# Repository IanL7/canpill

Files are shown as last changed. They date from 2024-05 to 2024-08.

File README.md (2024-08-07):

# canpill
Canpill is a basic development board based on Phil's Lab stm32 blue pill adaptation (https://www.youtube.com/watch?v=aVUqaB0IMh4). The board uses an STM32F103C8 microcontroller.

This repository contains the kicad project files and some basic software for the board.

## Image
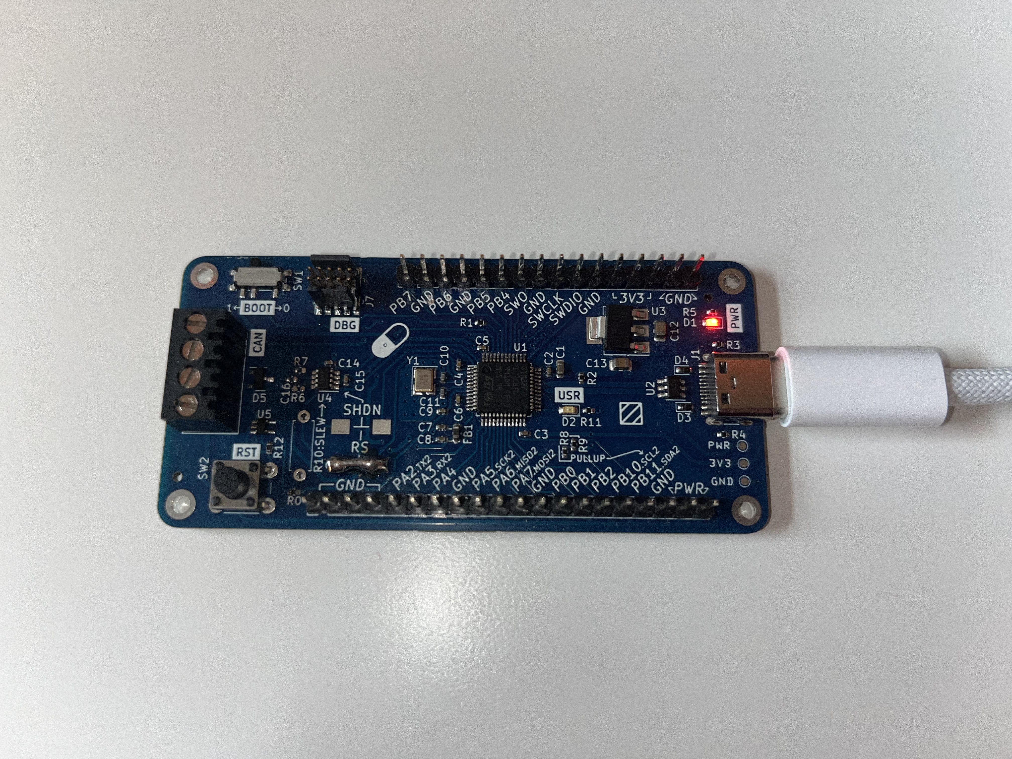
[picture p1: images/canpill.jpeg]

- Board manufactured before R13 was added

## Additions
- A CAN transceiver with screw terminal interface
- Additional header IO breakout
- 10 pin J-Link compatible connector
- Modified layout

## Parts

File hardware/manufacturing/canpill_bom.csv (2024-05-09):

Designator | Qnty | Comment | Footprint
C1 | 1 | 10u | Capacitor_SMD:C_0603_1608Metric
C2, C3, C4, C5, C9, C14, C15 | 7 | 100n | Capacitor_SMD:C_0402_1005Metric
C6 | 1 | 10n | Capacitor_SMD:C_0402_1005Metric
C7, C8 | 2 | 1u | Capacitor_SMD:C_0402_1005Metric
C10, C11 | 2 | 10p | Capacitor_SMD:C_0402_1005Metric
C12, C13 | 2 | 22u | Capacitor_SMD:C_0805_2012Metric
D1 | 1 | RED | LED_SMD:LED_0603_1608Metric
D2 | 1 | GREEN | LED_SMD:LED_0603_1608Metric
D3, D4 | 2 | D_Schottky | Diode_SMD:D_SOD-523
D5 | 1 | NUP2105L | Package_TO_SOT_SMD:SOT-23
FB1 | 1 | 120R | Inductor_SMD:L_0603_1608Metric
J1 | 1 | TYPE-C-31-M-12 | Connector_USB:USB_C_Receptacle_HRO_TYPE-C-31-M-12
R0, R1, R12 | 3 | 10k | Resistor_SMD:R_0402_1005Metric
R2, R5, R11 | 3 | 1k5 | Resistor_SMD:R_0402_1005Metric
R3, R4, R8, R9 | 4 | 5k1 | Resistor_SMD:R_0402_1005Metric
SW1 | 1 | SW_SPDT | Button_Switch_SMD:SW_SPDT_PCM12
SW2 | 1 | SW_Push | Button_Switch_THT:SW_PUSH_6mm
TP1, TP2, TP3 | 3 | TestPoint | TestPoint:TestPoint_Pad_D1.0mm
U1 | 1 | STM32F103C8T6 | Package_QFP:LQFP-48_7x7mm_P0.5mm
U2 | 1 | USBLC6-2SC6 | Package_TO_SOT_SMD:SOT-23-6
U3 | 1 | AMS1117-3.3 | Package_TO_SOT_SMD:SOT-223-3_TabPin2
U4 | 1 | MAX3051EKA+T | Package_TO_SOT_SMD:SOT-23-8
U5 | 1 | 74AHC1G08GW-Q100,1 | 74AHC1G08GW_Q100_1-2:SOT65P210X110-5N
Y1 | 1 | 16MHz | Crystal:Crystal_SMD_3225-4Pin_3.2x2.5mm

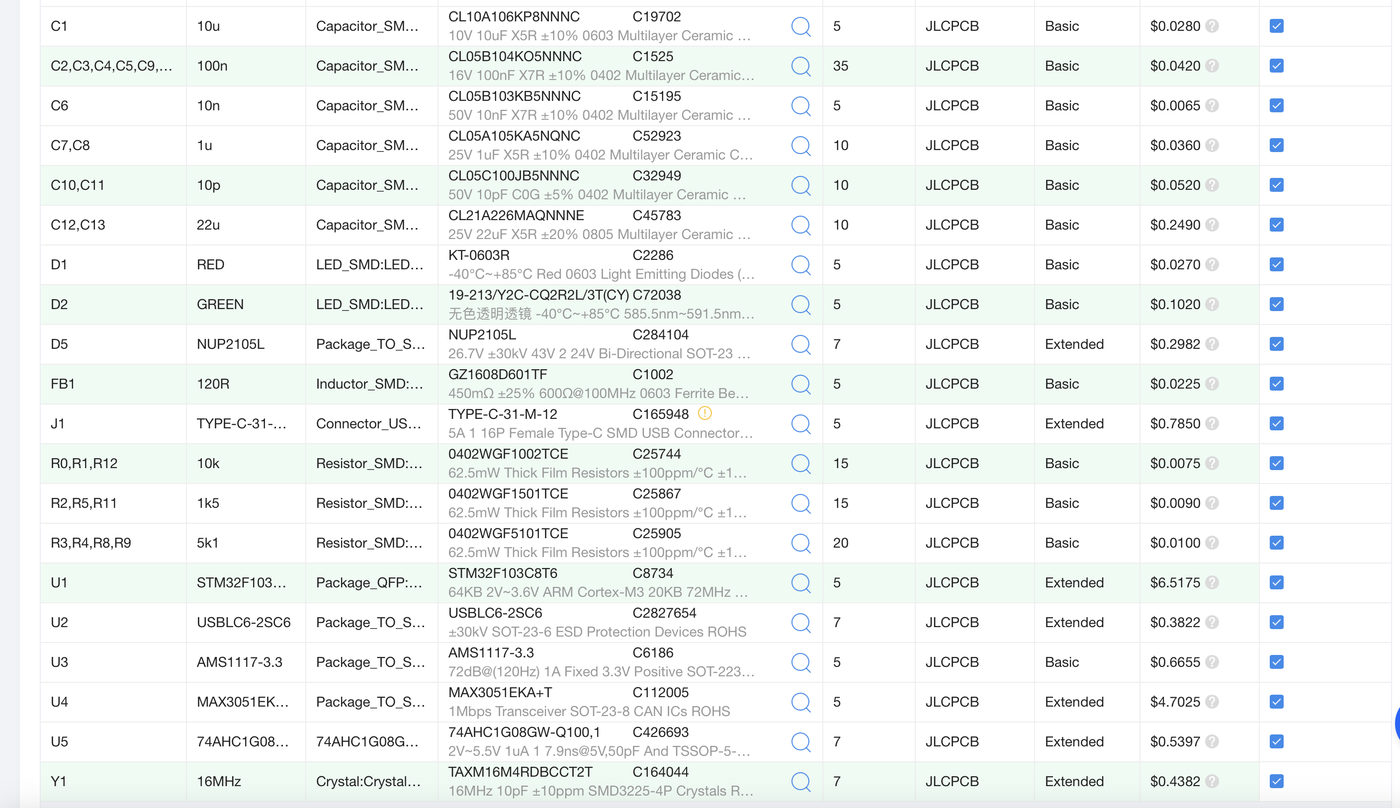
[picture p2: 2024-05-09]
hardware/docs/jlc_parts.png

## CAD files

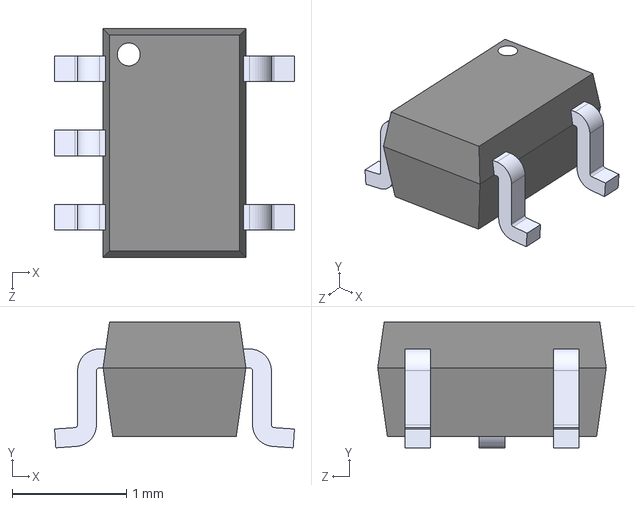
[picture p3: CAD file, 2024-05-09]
hardware/parts/74AHC1G08GW_Q100_1-2/74AHC1G08GW-Q100_1.step
2.10 x 1.10 x 2.00 mm

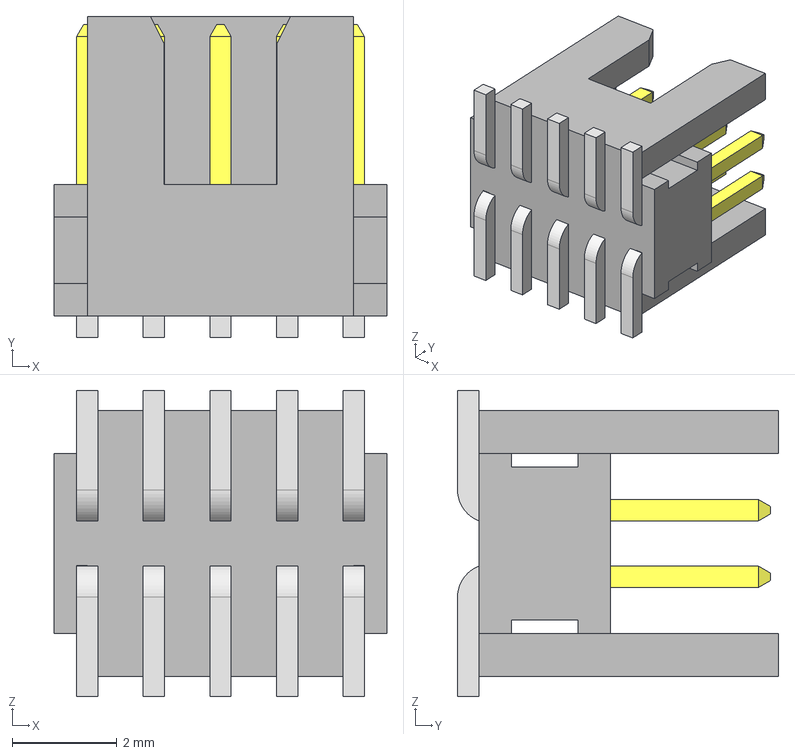
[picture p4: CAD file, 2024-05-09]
hardware/parts/FTSH-105-01-L-DV-K/FTSH-105-01-L-DV-K.stp
6.35 x 6.12 x 5.84 mm
FTSH-105-01-L-DV-K_body
FTSH-105-01-L-DV-K_pins1
FTSH-105-01-L-DV-K_pins2

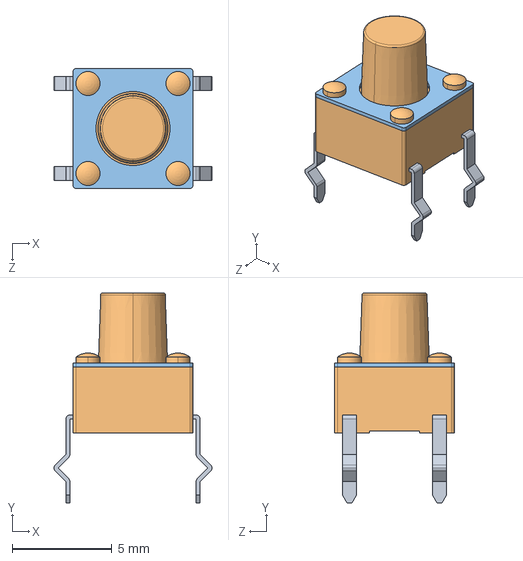
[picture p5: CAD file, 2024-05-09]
hardware/parts/TS02_66_70_BK_160_LCR_D/CUI_DEVICES_TS02-66-70-BK-160-LCR-D.step
7.90 x 10.5 x 6.00 mm

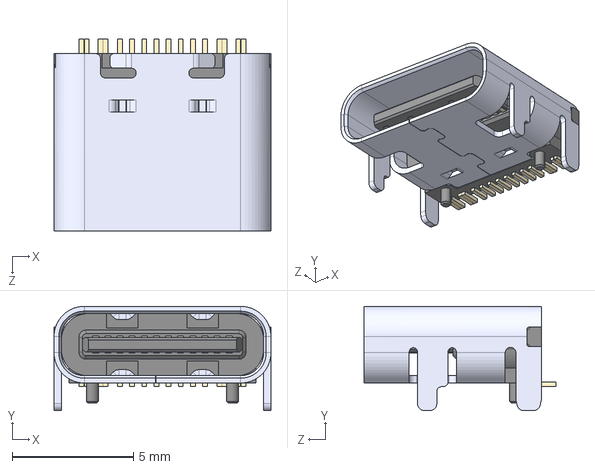
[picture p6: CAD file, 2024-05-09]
hardware/parts/TYPE-C-31-M-12--3DModel-STEP-56544.STEP
8.94 x 4.30 x 7.90 mm

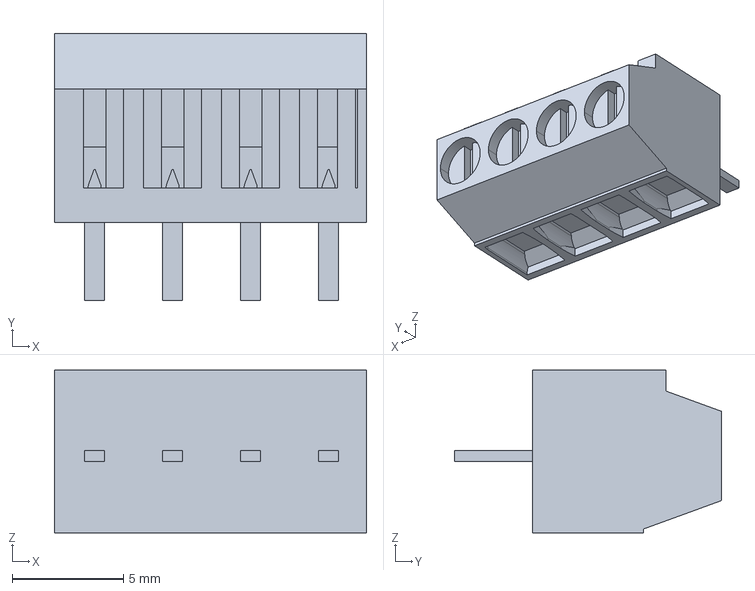
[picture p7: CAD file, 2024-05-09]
hardware/parts/1776112-4/1776112-4.step
14.0 x 12.0 x 7.30 mm

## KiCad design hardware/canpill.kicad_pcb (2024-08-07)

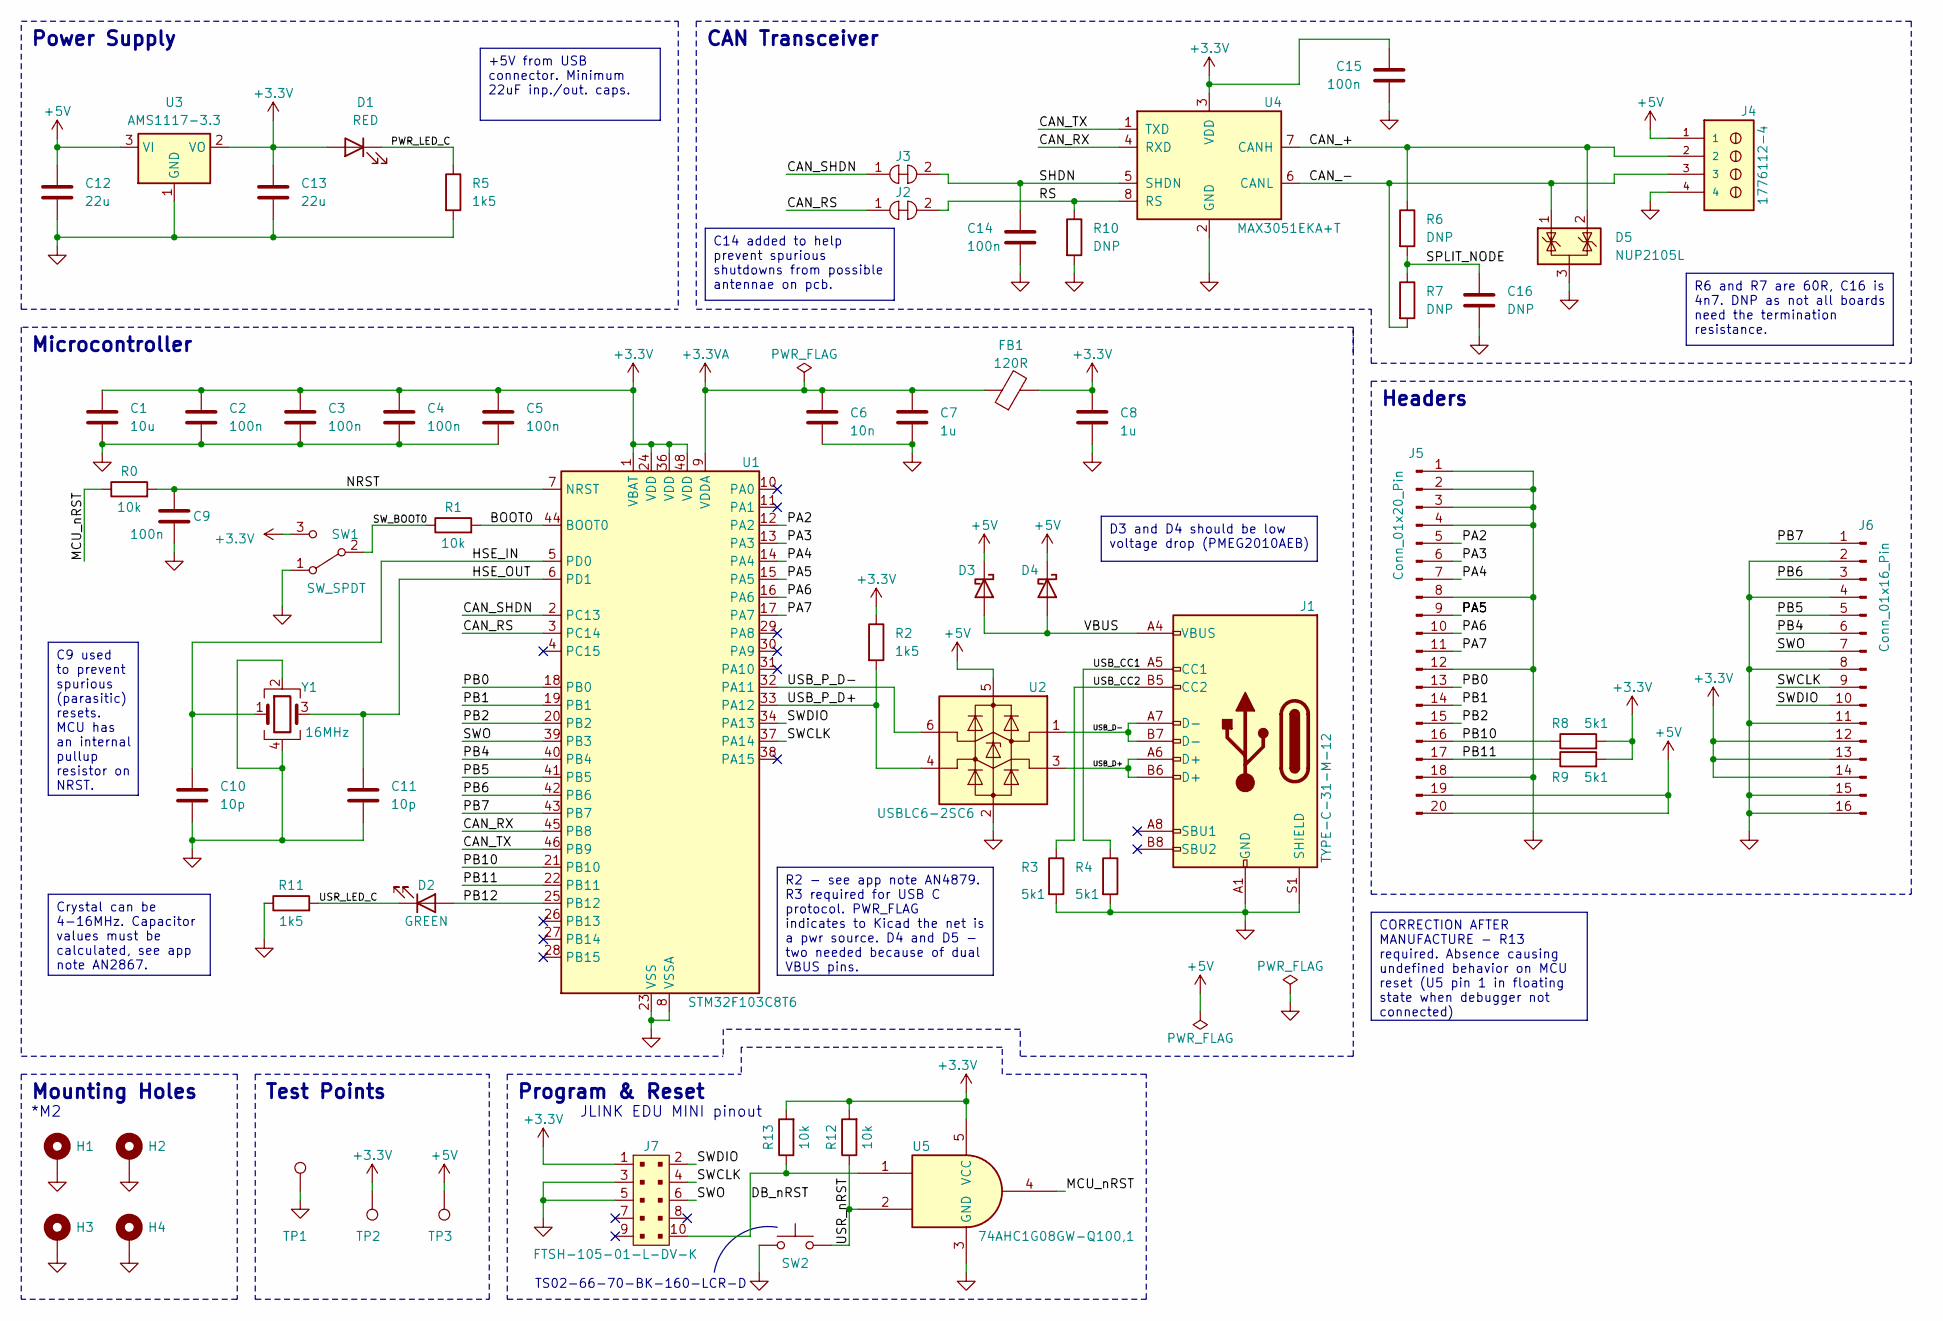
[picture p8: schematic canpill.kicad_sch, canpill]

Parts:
C1: 10u; C_0603_1608Metric
C2, C3, C4, C5, C9, C14, C15: 100n; C_0402_1005Metric
C6: 10n; C_0402_1005Metric
C7, C8: 1u; C_0402_1005Metric
C10, C11: 10p; C_0402_1005Metric
C12, C13: 22u; C_0805_2012Metric
C16: DNP; C_0402_1005Metric
D1: RED; LED_0603_1608Metric
D2: GREEN; LED_0603_1608Metric
D3, D4: D_Schottky; D_SOD-523
D5: NUP2105L; SOT-23
FB1: 120R; L_0603_1608Metric
H1, H2, H3, H4: MountingHole_Pad; MountingHole_2.2mm_M2_DIN965_Pad
J1: TYPE-C-31-M-12; USB_C_Receptacle_HRO_TYPE-C-31-M-12
J2, J3: 5100TR; Jumper_Micro-Miniature_P5.31mm; MPN 5100TR; Digi-Key_PN 36-5100CT-ND
J4: 1776112-4; TE_1776112-4; PARTREV R
J5: Conn_01x20_Pin; PinHeader_1x20_P2.54mm_Vertical
J6: Conn_01x16_Pin; PinHeader_1x16_P2.54mm_Vertical
J7: FTSH-105-01-L-DV-K; PinHeader_2x5_P1.27_SMD; MPN FTSH-105-01-L-DV-K; Digi-Key_PN SAM8799-ND
R0, R1, R12, R13: 10k; R_0402_1005Metric
R2, R5, R11: 1k5; R_0402_1005Metric
R3, R4, R8, R9: 5k1; R_0402_1005Metric
R6, R7: DNP; R_0402_1005Metric
R10: DNP; R_Axial_DIN0207_L6.3mm_D2.5mm_P7.62mm_Horizontal
SW1: SW_SPDT; SW_SPDT_PCM12
SW2: SW_Push; SW_PUSH_6mm
TP1, TP2, TP3: TestPoint; TestPoint_Pad_D1.0mm
U1: STM32F103C8T6; LQFP-48_7x7mm_P0.5mm
U2: USBLC6-2SC6; SOT-23-6
U3: AMS1117-3.3; SOT-223-3_TabPin2
U4: MAX3051EKA+T; SOT-23-8
U5: 74AHC1G08GW-Q100,1; SOT65P210X110-5N
Y1: 16MHz; Crystal_SMD_3225-4Pin_3.2x2.5mm

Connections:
+3.3V: C1.1, C2.1, C3.1, C4.1, C5.1, C8.1, C13.1, C15.1, D1.2 (A), FB1.2, J6.12, J6.13, J6.14, J7.1, R2.1, R8.2, R9.2, R12.2, R13.2, SW1.3 (C), TP2.1, U1.1 (VBAT), U1.24 (VDD), U1.36 (VDD), U1.48 (VDD), U3.2 (VO), U4.3 (VDD), U5.5 (VCC)
+3.3VA: C6.1, C7.1, FB1.1, U1.9 (VDDA)
+5V: C12.1, D3.1 (K), D4.1 (K), J4.1, J5.19, J5.20, TP3.1, U2.5 (VBUS), U3.3 (VI)
/BOOT0: R1.2, U1.44 (BOOT0)
/CAN_+: D5.2 (K), J4.2, R6.1, U4.7 (CANH)
/CAN_-: D5.1 (K), J4.3, R7.2, U4.6 (CANL)
/CAN_RS: J2.1, U1.3 (PC14)
/CAN_RX: U1.45 (PB8), U4.4 (RXD)
/CAN_SHDN: J3.1, U1.2 (PC13)
/CAN_TX: U1.46 (PB9), U4.1 (TXD)
/DB_nRST: J7.10, R13.1, U5.1
/HSE_IN: C10.1, U1.5 (PD0), Y1.1
/HSE_OUT: C11.1, U1.6 (PD1), Y1.3
/MCU_nRST: R0.1, U5.4
/NRST: C9.1, R0.2, U1.7 (NRST)
/PA2: J5.5, U1.12 (PA2)
/PA3: J5.6, U1.13 (PA3)
/PA4: J5.7, U1.14 (PA4)
/PA5: J5.9, U1.15 (PA5)
/PA6: J5.10, U1.16 (PA6)
/PA7: J5.11, U1.17 (PA7)
/PB0: J5.13, U1.18 (PB0)
/PB1: J5.14, U1.19 (PB1)
/PB2: J5.15, U1.20 (PB2)
/PB4: J6.6, U1.40 (PB4)
/PB5: J6.5, U1.41 (PB5)
/PB6: J6.3, U1.42 (PB6)
/PB7: J6.1, U1.43 (PB7)
/PB10: J5.16, R8.1, U1.21 (PB10)
/PB11: J5.17, R9.1, U1.22 (PB11)
/PB12: D2.2 (A), U1.25 (PB12)
/PWR_LED_C: D1.1 (K), R5.1
/RS: J2.2, R10.1, U4.8 (RS)
/SHDN: C14.1, J3.2, U4.5 (SHDN)
/SPLIT_NODE: C16.1, R6.2, R7.1
/SWCLK: J6.9, J7.4, U1.37 (PA14)
/SWDIO: J6.10, J7.2, U1.34 (PA13)
/SWO: J6.7, J7.6, U1.39 (PB3)
/SW_BOOT0: R1.1, SW1.2 (B)
/USB_CC1: J1.A5 (CC1), R4.1
/USB_CC2: J1.B5 (CC2), R3.1
/USB_D+: J1.A6 (D+), J1.B6 (D+), U2.3 (I/O1)
/USB_D-: J1.A7 (D-), J1.B7 (D-), U2.1 (I/O1)
/USB_P_D+: R2.2, U1.33 (PA12), U2.4 (I/O2)
/USB_P_D-: U1.32 (PA11), U2.6 (I/O2)
/USR_LED_C: D2.1 (K), R11.2
/USR_nRST: R12.1, SW2.2, U5.2
/VBUS: D3.2 (A), D4.2 (A), J1.A4 (VBUS), J1.A9 (VBUS), J1.B4 (VBUS), J1.B9 (VBUS)
GND: C1.2, C2.2, C3.2, C4.2, C5.2, C6.2, C7.2, C8.2, C9.2, C10.2, C11.2, C12.2, C13.2, C14.2, C15.2, C16.2, D5.3 (A), H1.1, H2.1, H3.1, H4.1, J1.A1 (GND), J1.A12 (GND), J1.B1 (GND), J1.B12 (GND), J1.S1 (SHIELD), J4.4, J5.1, J5.2, J5.3, J5.4, J5.8, J5.12, J5.18, J6.2, J6.4, J6.8, J6.11, J6.15, J6.16, J7.3, J7.5, R3.2, R4.2, R5.2, R10.2, R11.1, SW1.1 (A), SW2.1, TP1.1, U1.8 (VSSA), U1.23 (VSS), U1.35 (VSS), U1.47 (VSS), U2.2 (GND), U3.1 (GND), U4.2 (GND), U5.3 (GND), Y1.2, Y1.4

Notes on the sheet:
Crystal can be 4-16MHz. Capacitor values must be calculated, see app note AN2867.
C14 added to help prevent spurious shutdowns from possible antennae on pcb.
C9 used to prevent spurious (parasitic) resets. MCU has an internal pullup resistor on NRST.
D3 and D4 should be low voltage drop (PMEG2010AEB)
+5V from USB connector. Minimum 22uF inp./out. caps.
CORRECTION AFTER MANUFACTURE - R13 required. Absence causing undefined behavior on MCU reset (U5 pin 1 in floating state when debugger not connected)
R2 - see app note AN4879. R3 required for USB C protocol. PWR_FLAG indicates to Kicad the net is a pwr source. D4 and D5 - two needed because of dual VBUS pins.
R6 and R7 are 60R, C16 is 4n7. DNP as not all boards need the termination resistance.
Power Supply
TS02-66-70-BK-160-LCR-D
Mounting Holes
JLINK EDU MINI pinout
Headers
Microcontroller
*M2
Test Points
CAN Transceiver
Program & Reset

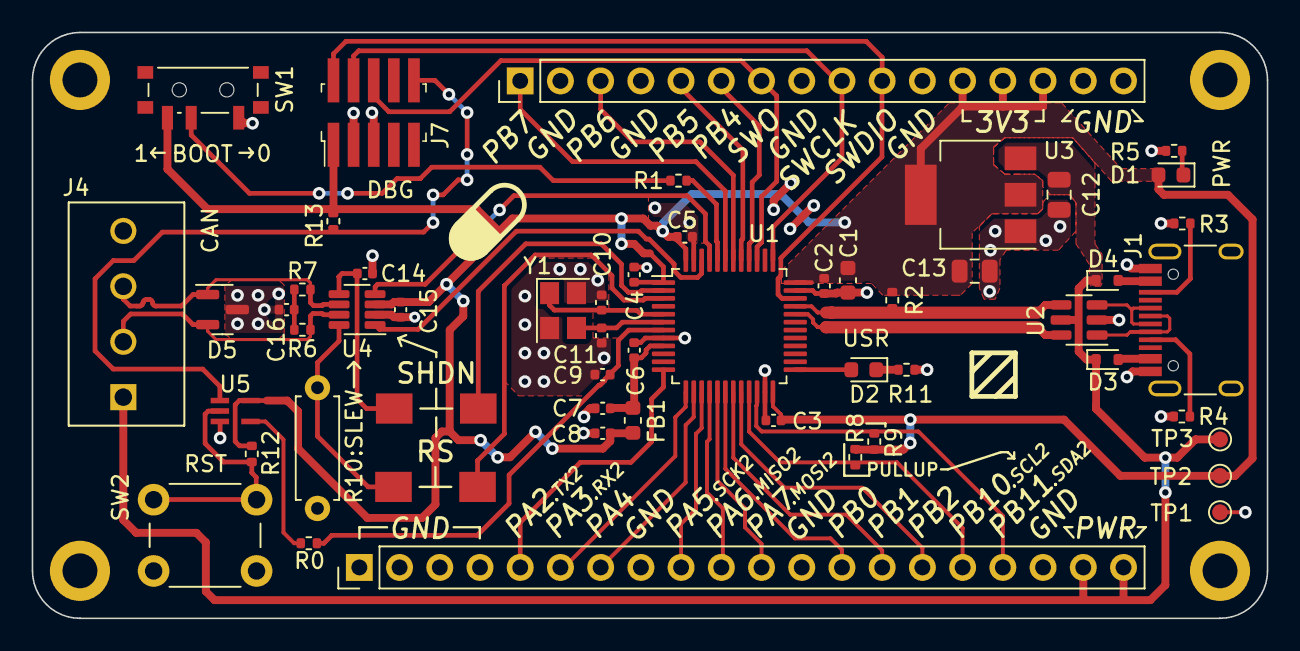
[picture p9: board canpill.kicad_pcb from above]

Board: 2 copper layers, 78.0 x 37.0 mm, 58 parts (0 on the bottom side), 49 nets.

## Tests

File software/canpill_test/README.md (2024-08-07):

# canpill_test

- Simple test program, toggles pin PB12 every 500ms (flash yellow LED)
- Boilerplate generated by STM32CubeMX
- Using VSCode with Cortex-Debug extension, cmake, and segger j-link

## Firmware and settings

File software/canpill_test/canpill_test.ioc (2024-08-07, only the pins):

Mcu.UserName=STM32F103C8Tx
PA13.Signal=SYS_JTMS-SWDIO
PA14.Signal=SYS_JTCK-SWCLK
PB12.Signal=GPIO_Output
PB3.Signal=SYS_JTDO-TRACESWO
PD0-OSC_IN.Signal=RCC_OSC_IN
PD1-OSC_OUT.Signal=RCC_OSC_OUT

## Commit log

2024-05-09 remove xml
    [canpill.kicad_pcb]
2024-08-07 (software:canpill_test) initial commit; (hardware) add pull-up on DB_nRST
    [canpill.kicad_pcb, canpill.kicad_sch]

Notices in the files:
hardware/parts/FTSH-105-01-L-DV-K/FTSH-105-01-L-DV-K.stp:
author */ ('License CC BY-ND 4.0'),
